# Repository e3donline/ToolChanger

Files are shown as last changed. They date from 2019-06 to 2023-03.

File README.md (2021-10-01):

# ToolChanger
STPs / STLs / DXFs / PDFs

Copyright (C) E3D-Online Ltd (e3d-online.com)
These files are free hardware you can redistribute it and / or
modify it under the terms of the General Public License as
published by the Free Software Foundation, either version 3 of
the License, or (at your option) any later version.

01/10/21 - Added Super Volcano Fan Duct

15/03/21 - Added Hemera Direct Drive Tool Files

10/02/21 - Added Hemera Bowden Brackets

24/02/20 - Added modified V6 Fan Duct STL for Winsinn Fans

05/08/19 - Added README.md to the STLs folders  

31/07/19 - Added step files for printed parts

30/07/19 - Added Volcano PCF Duct

11/07/19 - Added V6 Dock Cables(Mirror)

11/07/19 - Updated V6 PCF Duct

26/06/19 - Added V6 Tool components

25/06/19 - Corrections to TC-FACE

24/06/19 - Intital Upload

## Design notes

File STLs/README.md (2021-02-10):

Print the required number of parts as listed below.

1 x Tool-Changer Cover Body.stl  

      Tool-Changer Cover Dot.stl  
      Tool-Changer Cover Long.stl  
      Tool-Changer Cover Triangle.stl  

1 x X-Carriage Cable Bracket.stl  
1 x X-Carriage Cables.stl   
2 x Hemera Bowden Bracket.stl

Typical slicer settings.  
   
0.20 Layer height.  
0.40 Nozzle.  
3 Perimeters.  
5 Top Layers.  
5 Bottom Layers.  
12% Infil.  

Print with your favourite material.

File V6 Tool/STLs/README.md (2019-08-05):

Print the required number of parts as listed below (for four V6 Bowden Tools).

4 x V6 Cable Support.stl   
4 x V6 PCF Fan Bracket.stl   
4 x V6 Receiver Top.stl   
4 x V6 PCF Duct.stl (Print from Hight-Temperature material).   
2 x V6 Dock Cables(Mirror).stl   
2 x V6 Dock Cables.stl   

Volcano PCF Duct.stl  (Use this fan duct if you are using a Volcano).   

Typical slicer settings.  
   
0.20 Layer height.  
0.40 Nozzle.  
3 Perimeters.  
5 Top Layers.  
5 Bottom Layers.  
12% Infil.  

Print with your favourite material.

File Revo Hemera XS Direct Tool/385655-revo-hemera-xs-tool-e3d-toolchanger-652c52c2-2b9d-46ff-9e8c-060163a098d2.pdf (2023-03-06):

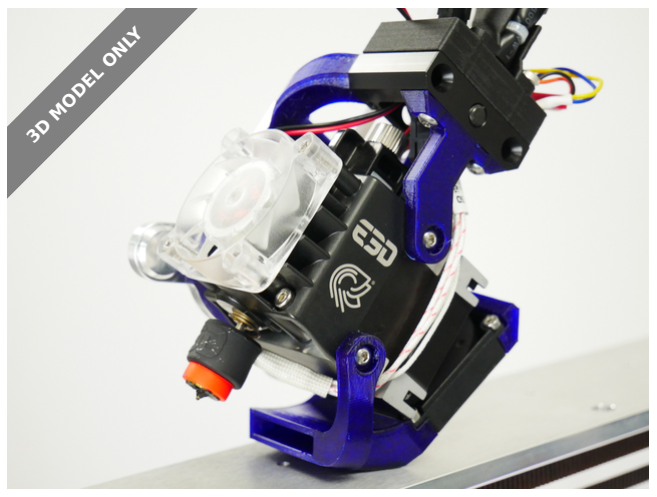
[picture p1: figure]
3D MODEL ONLY

Summary

All the printed parts needed to create the Revo Hemera XS Tool.

3D Printers (https://printables.com/model?categoryId=1) > 3D Printers - Upgrades (https://printables.com/model?categoryId=2)

These are the printable parts for the Revo Hemera XS Tool for E3D's Toolchanger platform.

A mirrored version is provided but be aware, you will lose some build volume in the Y direction (around 10mm) if you choose to use this configuration.

No supports are needed for any of these parts.

Many of the holes need reaming/tapping.

If upgrading from original V6 Hemera tools, please note:

Z offsets have changed by around 11mm from the original V6 Hemera tool so be sure to account for this in your config.g to avoid crashing into the print bed.
The X position of the Toolplate has moved by around 12.5mm to the right. You will need to account for this in your tfree.g and tpre.g files. Note: the offset for the mirrored version will be different.
The Y position of the Toolplate remains the same.

E3D (https://printables.com/social/193579/about)

Revo Hemera XS

Tool - E3D

Toolchanger

VIEW IN BROWSER (https://printables.com/model/385655-revo-hemera-xs-tool-e3d-toolchanger)

updated 27. 2. 2023 | published 27. 2. 2023

•

•

•

### Model files

- Regular Tool | 12 files

blower⁻fan⁻duct.stl

blower⁻fan⁻holder⁻arm.stl

dock-to⁻rhxs.stl

dock-brace.stl

toolplate⁻to⁻rhxs.stl

docking-station.stl

dock-to⁻rhxs.step

blower⁻fan⁻holder⁻arm.step

toolplate⁻to⁻rhxs.step

dock-brace.step

blower⁻fan⁻duct.step

docking-station.step

- Mirrored Tool | 12 files

blower⁻fan⁻duct⁻m.stl

blower⁻fan⁻holder⁻arm⁻m.stl

dock-to⁻rhxs⁻m.stl

dock-brace⁻m.stl

toolplate⁻to⁻rhxs⁻m.stl

docking-station⁻m.stl

blower⁻fan⁻duct⁻m.step

blower⁻fan⁻holder⁻arm⁻m.step

dock-to⁻rhxs⁻m.step

dock-brace⁻m.step

toolplate⁻to⁻rhxs⁻m.step

docking-station⁻m.step

receiver⁻top.stl

License

This work is licensed under a
Creative Commons (4.0 International License)

Attribution⁻ShareAlike (http://creativecommons.org/licenses/by-sa/4.0/)

✖ | Sharing without ATTRIBUTION
✔ | Remix Culture allowed
✔ | Commercial Use
✔ | Free Cultural Works
✔ | Meets Open Definition

cable⁻support.stl

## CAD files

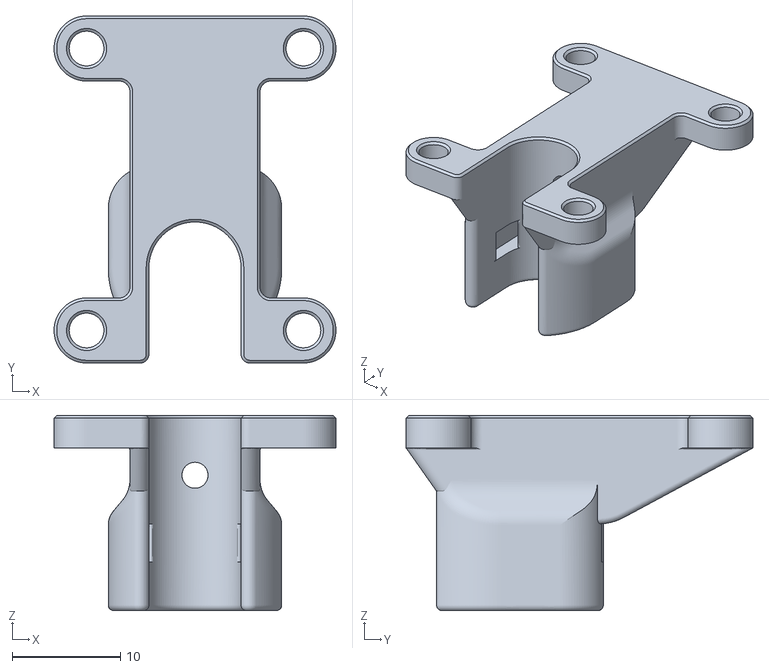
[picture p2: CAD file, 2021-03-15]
Hemera Direct Tool/STLs/V6_Cable_Support.stl
26.0 x 32.0 x 18.0

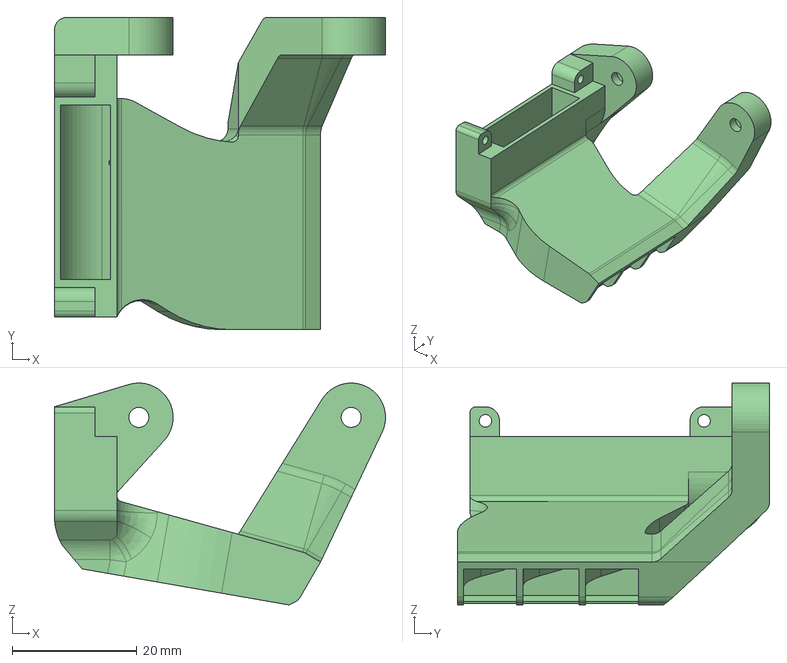
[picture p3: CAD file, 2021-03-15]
Hemera Direct Tool/STPs/Hemera_PCF_Duct_-_Volcano.step
53.0 x 50.0 x 35.5 mm

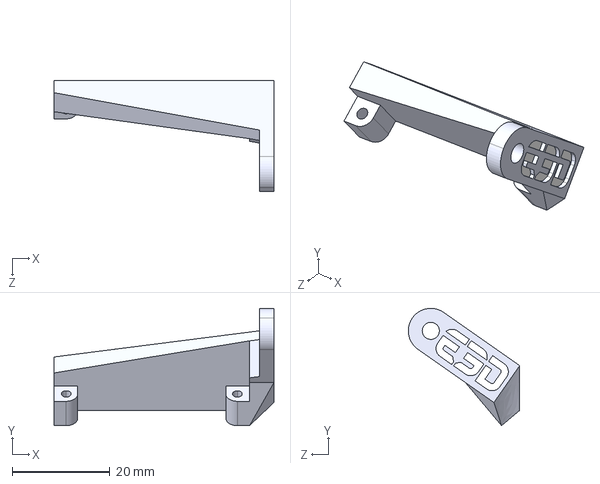
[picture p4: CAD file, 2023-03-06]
Revo Hemera XS Direct Tool/Mirrored Tool/STPs/Blower fan holder arm (M).STEP
45.0 x 24.0 x 22.8 mm

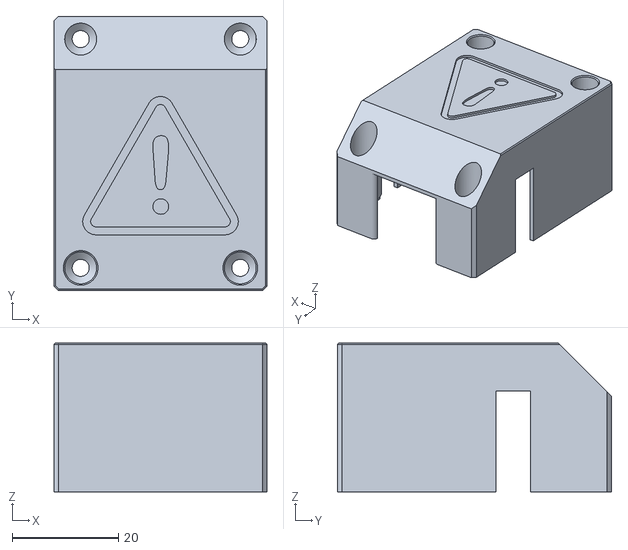
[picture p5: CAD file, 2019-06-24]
STLs/Tool-Changer Cover Body.stl
40.0 x 51.5 x 28.0

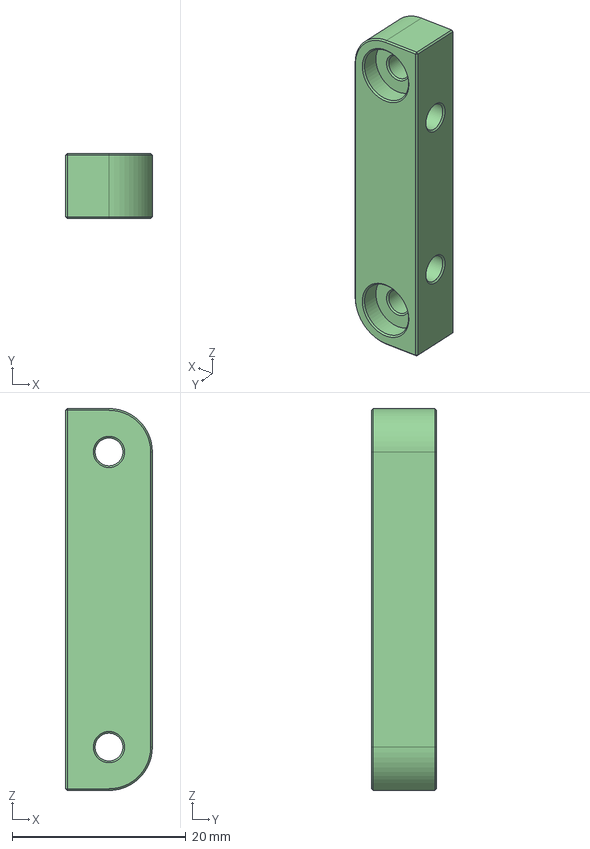
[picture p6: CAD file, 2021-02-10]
STPs/Hemera Bowden Bracket.step
10.0 x 7.50 x 44.0 mm

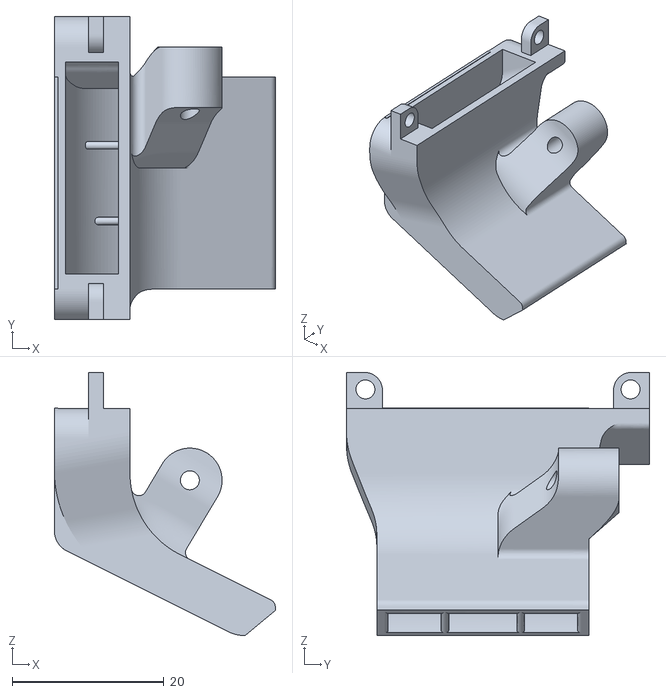
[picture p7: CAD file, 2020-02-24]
V6 Tool/STLs/V6 PCF Duct (Winsinn).stl
29.2 x 40.0 x 34.8

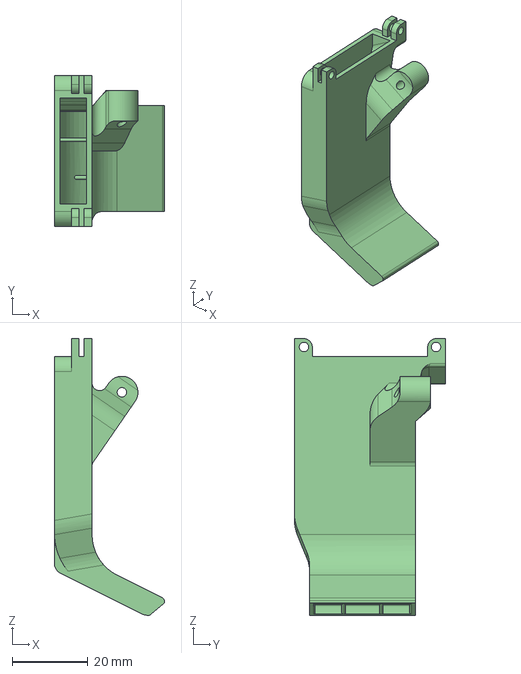
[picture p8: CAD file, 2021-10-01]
V6 Tool/STPs/Super Volcano PCF Duct.step
29.2 x 40.0 x 73.3 mm

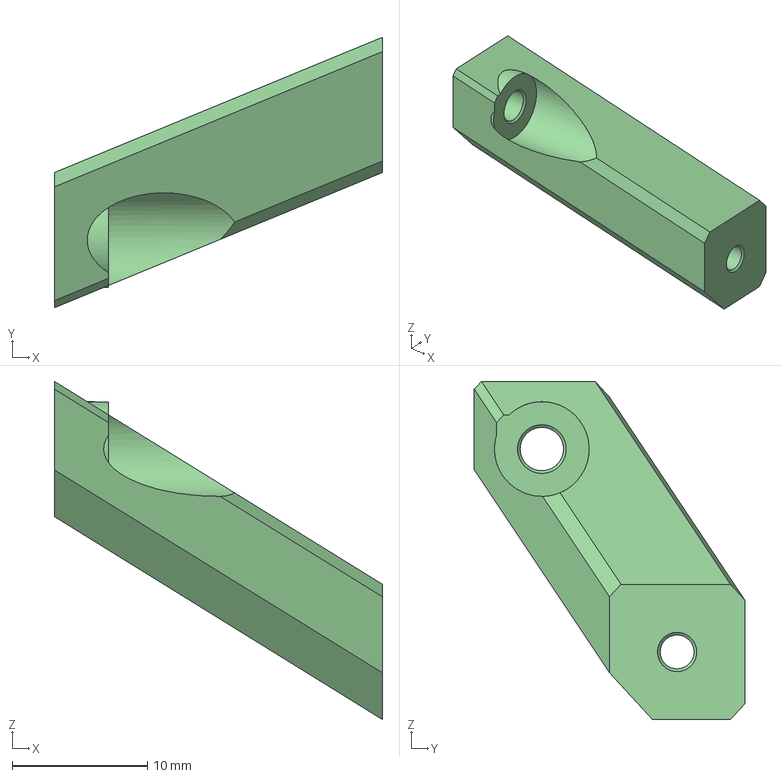
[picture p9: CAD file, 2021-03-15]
Hemera Direct Tool/STPs/TC-V6-HEMERA-DOCK-BRACE.step
24.2 x 20.0 x 25.0 mm

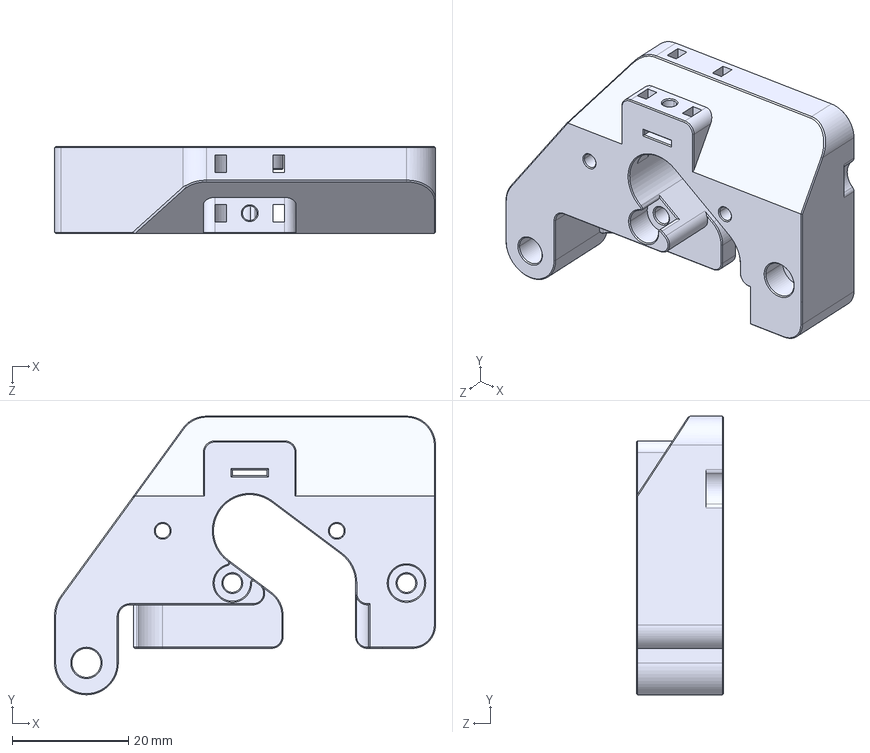
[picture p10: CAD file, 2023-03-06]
Revo Hemera XS Direct Tool/Mirrored Tool/STPs/Docking Station (M).STEP
65.6 x 48.0 x 15.0 mm

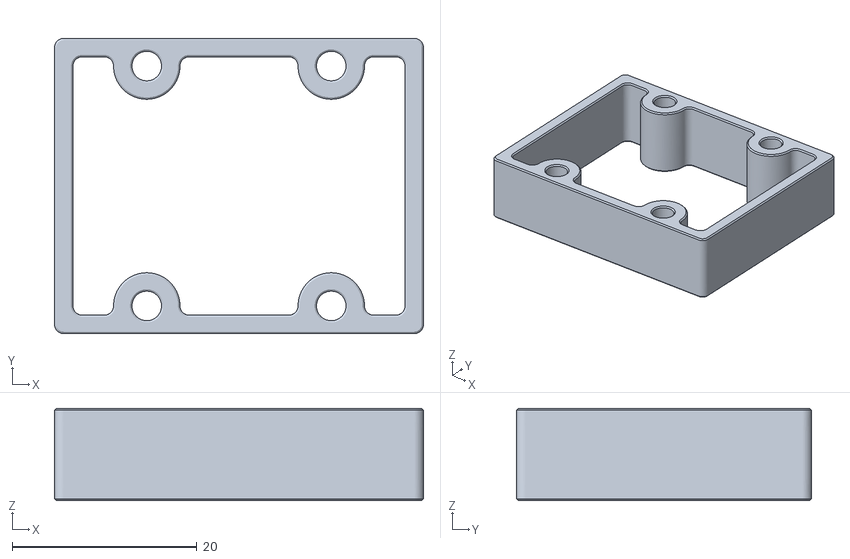
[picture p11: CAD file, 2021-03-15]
Revo Hemera XS Direct Tool/Receiver Top.stl
40.0 x 32.0 x 10.0

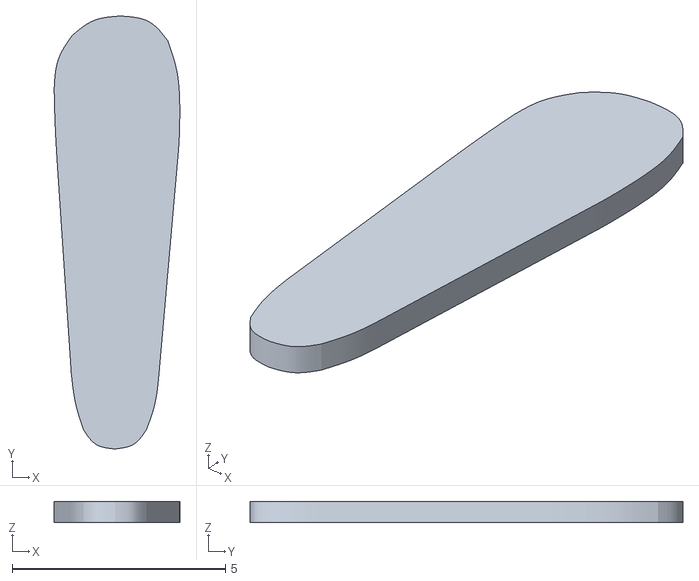
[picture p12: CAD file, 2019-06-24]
STLs/Tool-Changer Cover Long.stl
2.95 x 10.2 x 0.5

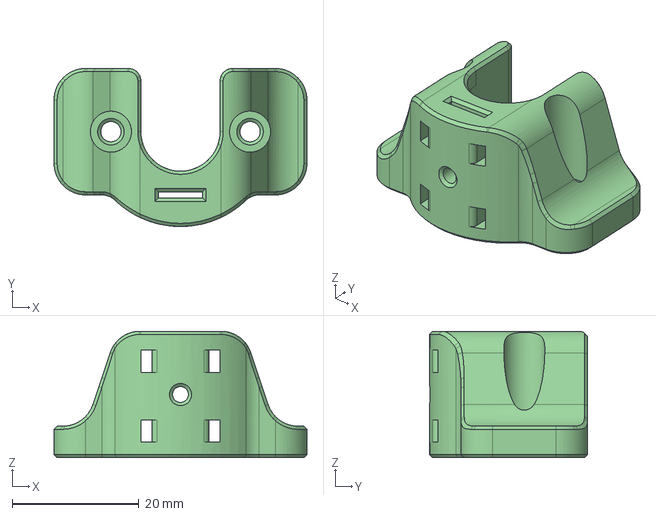
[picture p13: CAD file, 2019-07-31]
STPs/X-Carriage Cable Bracket.step
40.0 x 25.0 x 20.0 mm

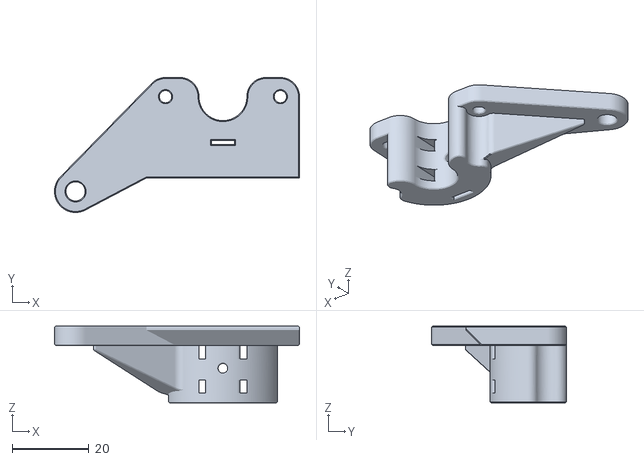
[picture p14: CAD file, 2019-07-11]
V6 Tool/STLs/V6 Dock Cables(Mirror).stl
64.0 x 35.2 x 20.0

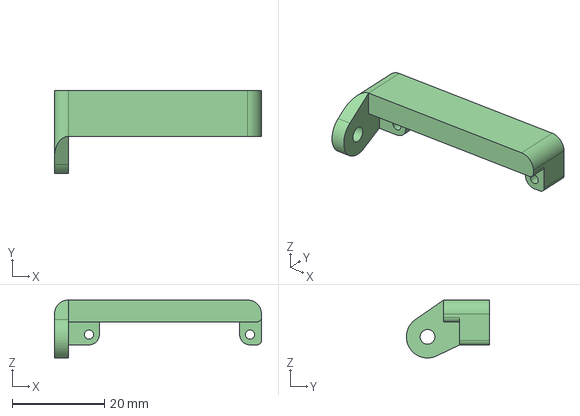
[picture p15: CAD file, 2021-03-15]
Hemera Direct Tool/STPs/Hemera_PCF_Bracket.step
45.0 x 18.1 x 12.6 mm

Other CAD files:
Revo Hemera XS Direct Tool/Cable Support.stl
Revo Hemera XS Direct Tool/Regular Tool/STPs/Blower fan holder arm.STEP
Revo Hemera XS Direct Tool/Regular Tool/STPs/Docking station.STEP
V6 Tool/STPs/V6 Dock Cables.step
Hemera Direct Tool/STLs/Hemera_PCF_Bracket.stl
Hemera Direct Tool/STLs/Hemera_PCF_Duct_-_V6.stl
Hemera Direct Tool/STLs/Hemera_PCF_Duct_-_Volcano.stl
Hemera Direct Tool/STLs/TC-DOCK-V6-DOCK-ADAPTER.stl
Hemera Direct Tool/STLs/TC-HEMERA-PLATE-ADAPTER.stl
Hemera Direct Tool/STLs/TC-V6-DOCK-BRACKET-HEMERA-ADAPTER.stl
Hemera Direct Tool/STLs/TC-V6-HEMERA-DOCK-BRACE-V2.stl
Hemera Direct Tool/STLs/TC-V6-HEMERA-DOCK-BRACE.stl
Hemera Direct Tool/STPs/Hemera_PCF_Duct_-_V6.step
Hemera Direct Tool/STPs/TC-DOCK-V6-DOCK-ADAPTER.step
Hemera Direct Tool/STPs/TC-HEMERA-PLATE-ADAPTER.step
Hemera Direct Tool/STPs/TC-V6-DOCK-BRACKET-HEMERA-ADAPTER.step
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

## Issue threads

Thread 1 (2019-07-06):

Tool Head Face Plate Assembly has wrong dowel pin dimensions

jannau, 2019-07-06:
The dowel pins are listed as `1mm x 4mm`. `10mm x 4mm` seems to match the dimensions of the face plate.

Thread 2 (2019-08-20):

BOM in TC-COUPLER-KIT has errors

nraynaud, 2019-08-20:
- Item 7 is probably 6 M3 standoffs
- Item 8 is probably an error there are probably no M4 screws at all anywhere

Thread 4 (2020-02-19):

V6 PCF Duct does not fit the new pwm ready fan's shipped

arhi, 2020-02-19:
new pwm enable fans shipped as a replacement for old fan's that had issues with pwm have fatter lip and can't fit the existing V6 PCF Duct.stl

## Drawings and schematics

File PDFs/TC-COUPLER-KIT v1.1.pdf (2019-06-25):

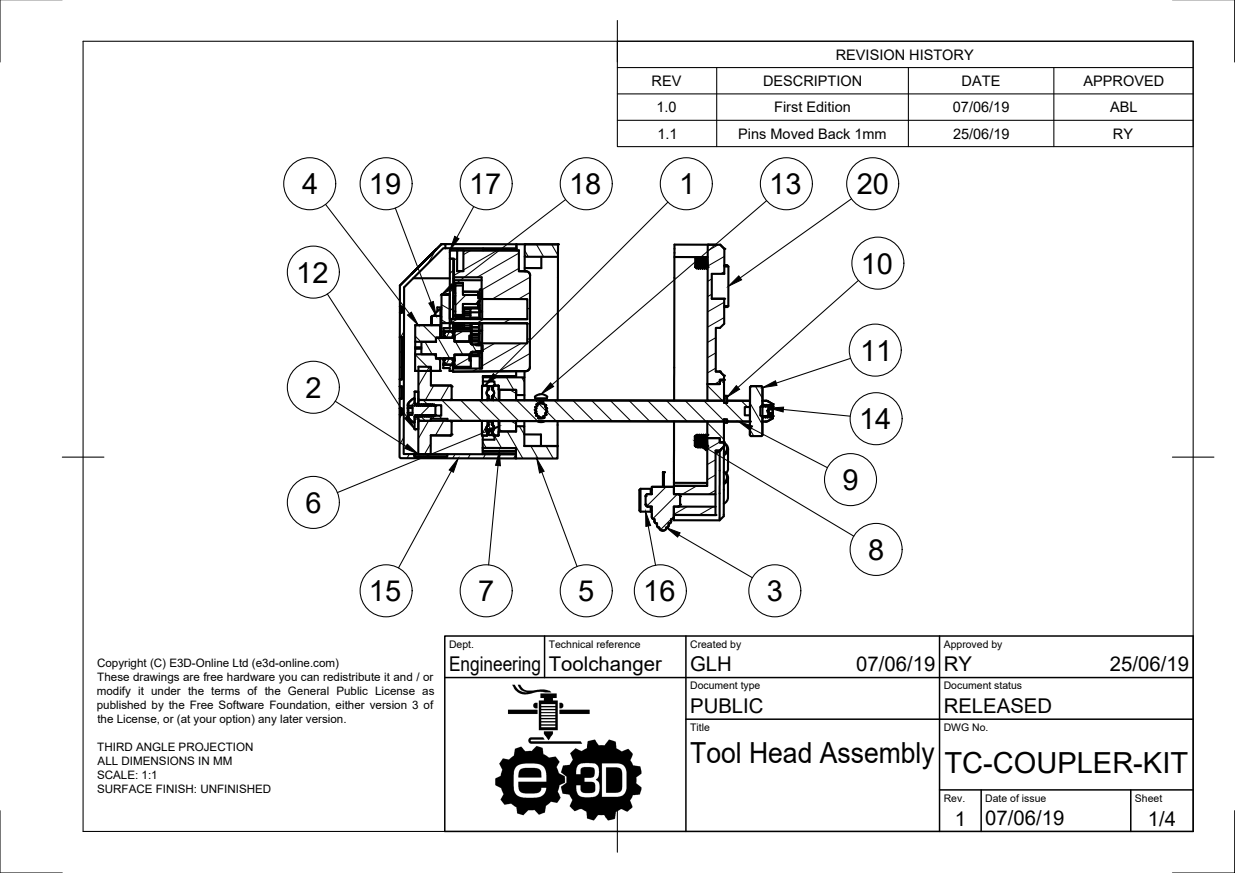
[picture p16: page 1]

REVISION HISTORY

REV | DESCRIPTION | DATE | APPROVED
1.0 | First Edition | 07/06/19 | ABL
1.1 | Pins Moved Back 1mm | 25/06/19 | RY

Dept. Engineering | Technical reference Toolchanger | Created by GLH 07/06/19 | Approved by RY 25/06/19

Copyright (C) E3D-Online Ltd (e3d-online.com)
These drawings are free hardware you can redistribute it and / or modify it under the terms of the General Public License as published by the Free Software Foundation, either version 3 of

Document type PUBLIC | Document status RELEASED

the License, or (at your option) any later version.

Title | DWG No. TC-COUPLER-KIT Tool Head Assembly

THIRD ANGLE PROJECTION
ALL DIMENSIONS IN MM
SCALE: 1:1
SURFACE FINISH: UNFINISHED

Rev. 1 | Date of issue 07/06/19 | Sheet

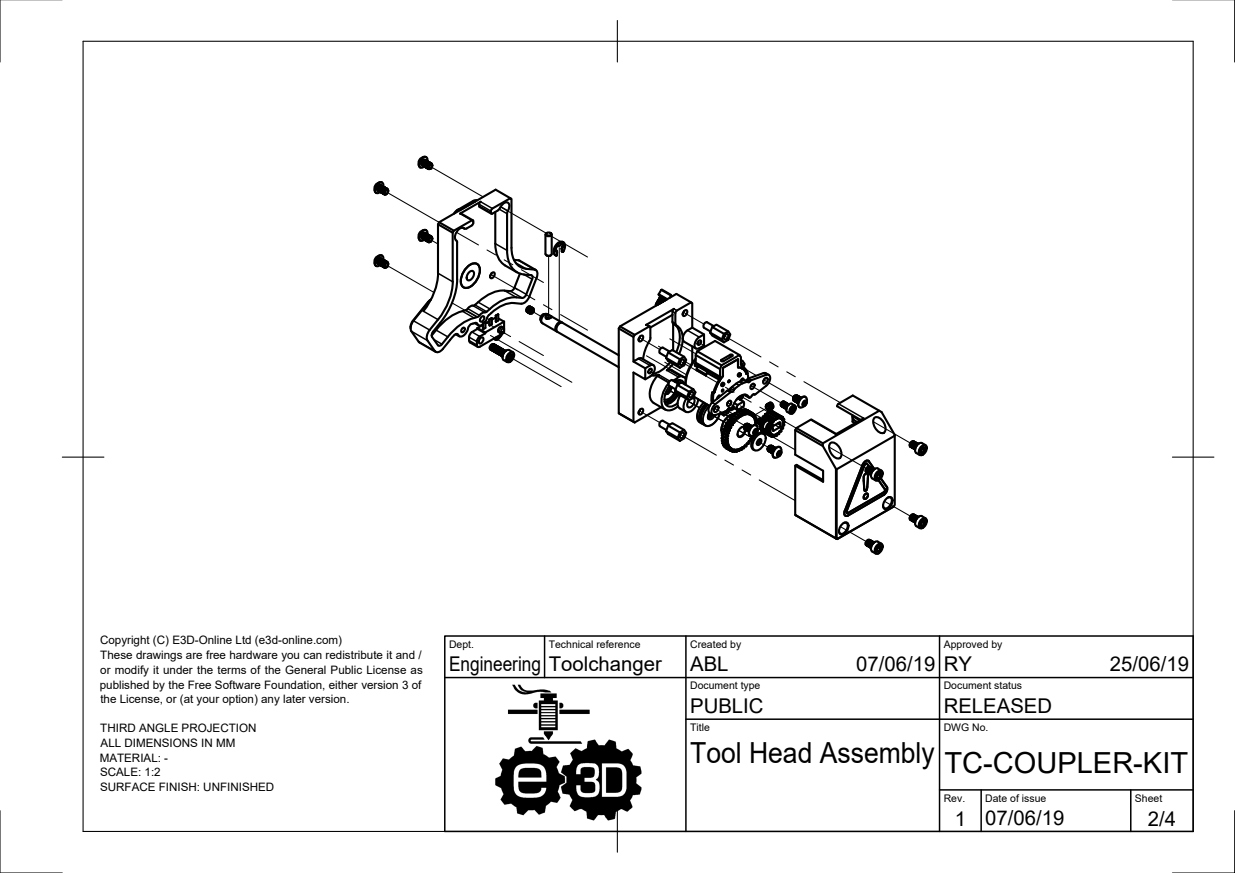
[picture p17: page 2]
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

Dept. Engineering | Technical reference Toolchanger | Created by ABL 07/06/19 | Approved by RY 25/06/19

Document type PUBLIC | Document status RELEASED

the License, or (at your option) any later version.

THIRD ANGLE PROJECTION
ALL DIMENSIONS IN MM
MATERIAL: -
SCALE: 1:2
SURFACE FINISH: UNFINISHED

Title | DWG No. TC-COUPLER-KIT Tool Head Assembly

Rev. | Date of issue | Sheet

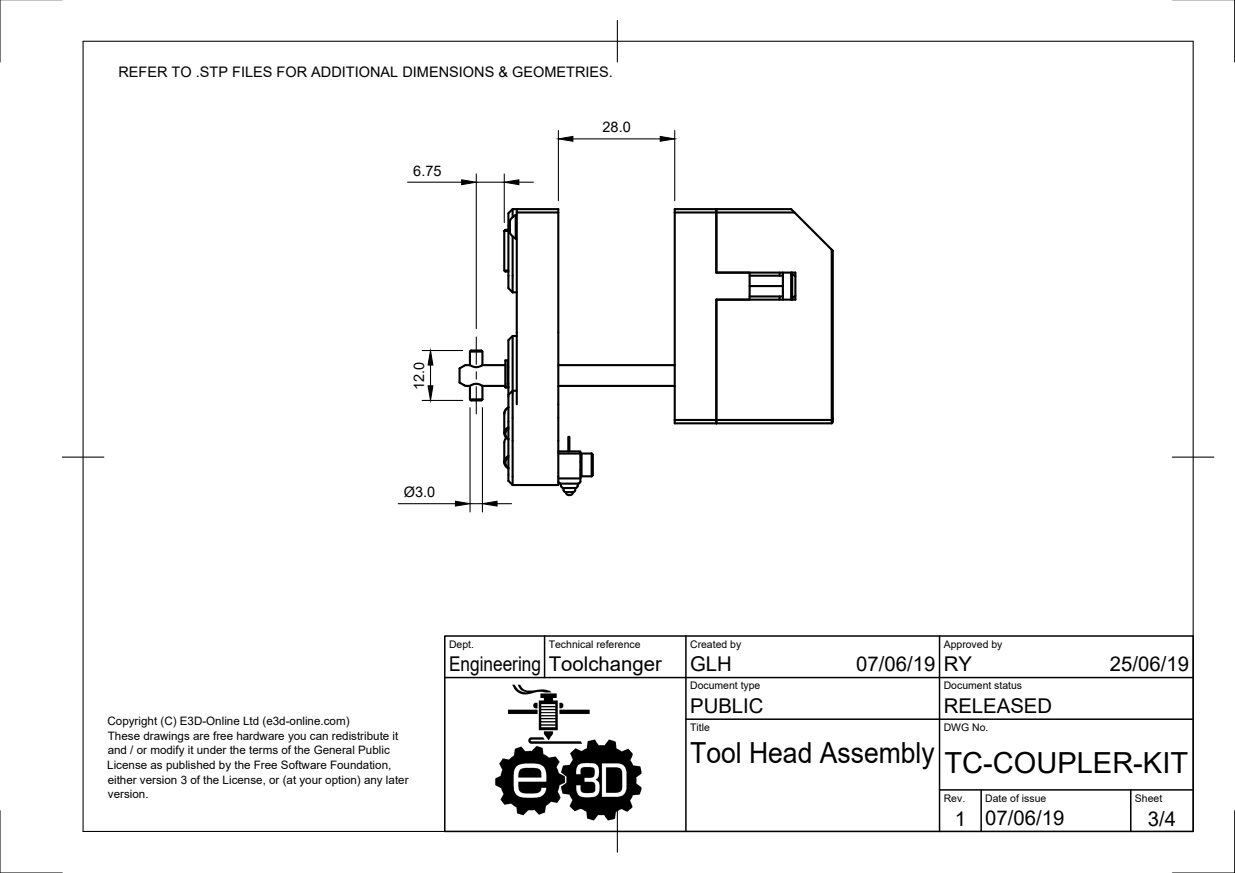
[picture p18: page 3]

REFER TO .STP FILES FOR ADDITIONAL DIMENSIONS & GEOMETRIES.

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

Document type PUBLIC | Document status RELEASED

Copyright (C) E3D-Online Ltd (e3d-online.com)
These drawings are free hardware you can redistribute it
and / or modify it under the terms of the General Public
License as published by the Free Software Foundation,
either version 3 of the License, or (at your option) any later
version.

Title | DWG No. TC-COUPLER-KIT Tool Head Assembly

Rev. | Date of issue | Sheet

Dept. Engineering | Technical reference Toolchanger | Created by GLH 07/06/19 | Approved by RY 25/06/19
| | Document type PUBLIC | Document status RELEASED
| | Title | DWG No. TC-COUPLER-KIT Tool Head Assembly
Rev. | Date of issue | Sheet

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

### Parts List

Item | Qty | Description
1 | 1 | F5-12M Thrust Bearing
2 | 1 | 40T Gear M0D 0.5
3 | 1 | Endstop Switch
4 | 1 | 20T Gear MOD 0.5
5 | 1 | TC-BACK
6 | 1 | MR105RS Bearing
7 | 1 | 8mm Standoff
8 | 7 | M4 5mm Button Head Screw
9 | 1 | Tool Coupler Shaft
10 | 1 | E-Clip
11 | 1 | 12mm x 3mm Dowel Pin
12 | 1 | M3 Washer
13 | 5 | M3 4mm Socket Head Screw
14 | 2 | M3 3mm Grub Screw
15 | 1 | Printed Cover
16 | 1 | M3 10mm Socket Head Screw
17 | 1 | Stepper Motor
18 | 1 | Motor Bracket
19 | 2 | M2.5 5mm Socket Head Screw
20 | 1 | TC-FACE-AS

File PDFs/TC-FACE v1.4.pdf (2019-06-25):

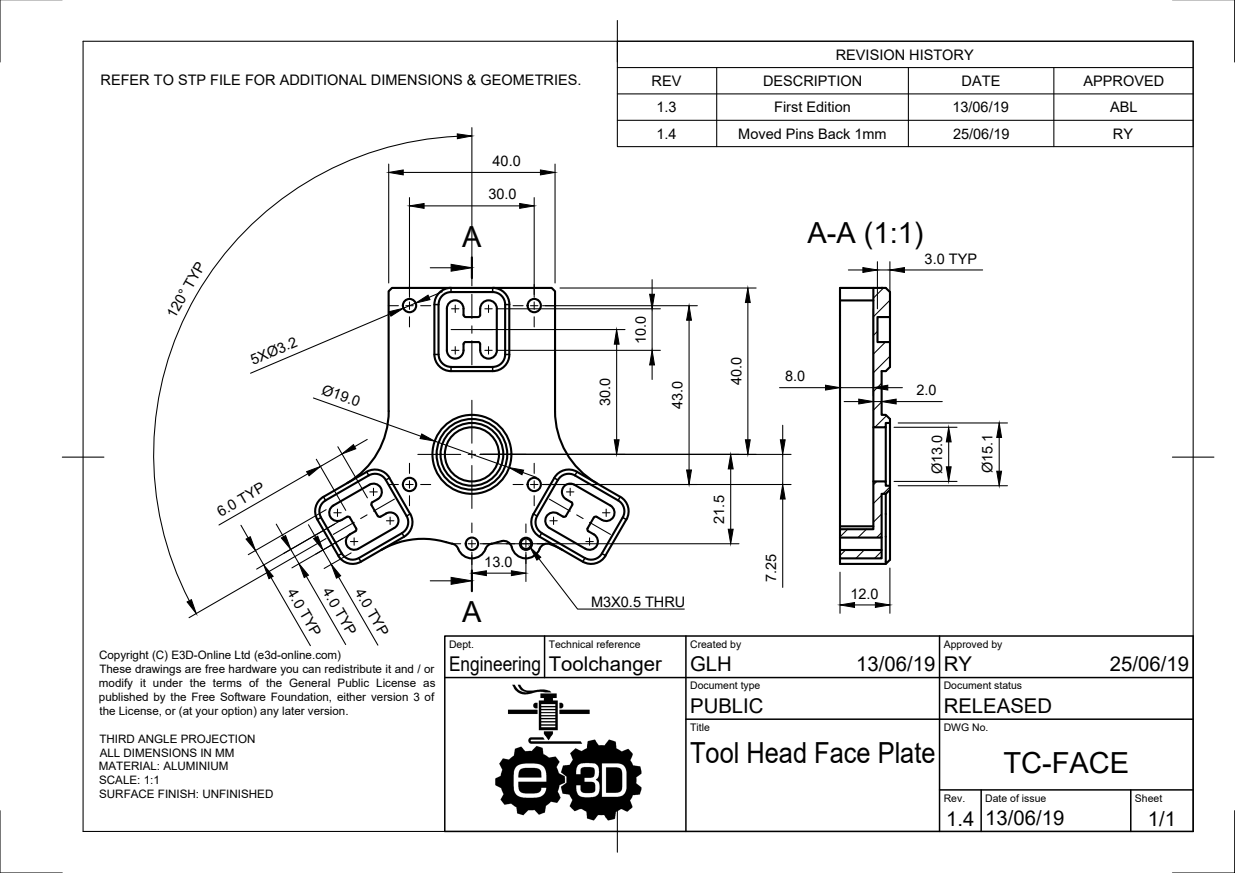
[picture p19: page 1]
M3X0.5 THRU; 120° TYP 43.0 Ø13.0 Ø15.1; 3.0 TYP; 6.0 TYP

REVISION HISTORY

REFER TO STP FILE FOR ADDITIONAL DIMENSIONS & GEOMETRIES.

REV | DESCRIPTION | DATE | APPROVED
1.3 | First Edition | 13/06/19 | ABL
1.4 | Moved Pins Back 1mm | 25/06/19 | RY

4.0 TYP 4.0 TYP 4.0 TYP

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

Dept. Engineering | Technical reference Toolchanger | Created by GLH 13/06/19 | Approved by RY 25/06/19

Document type PUBLIC | Document status RELEASED

the License, or (at your option) any later version.

Title | DWG No. TC-FACE Tool Head Face Plate

THIRD ANGLE PROJECTION
ALL DIMENSIONS IN MM
MATERIAL: ALUMINIUM
SCALE: 1:1
SURFACE FINISH: UNFINISHED

Rev. 1.4 | Date of issue 13/06/19 | Sheet 1/1

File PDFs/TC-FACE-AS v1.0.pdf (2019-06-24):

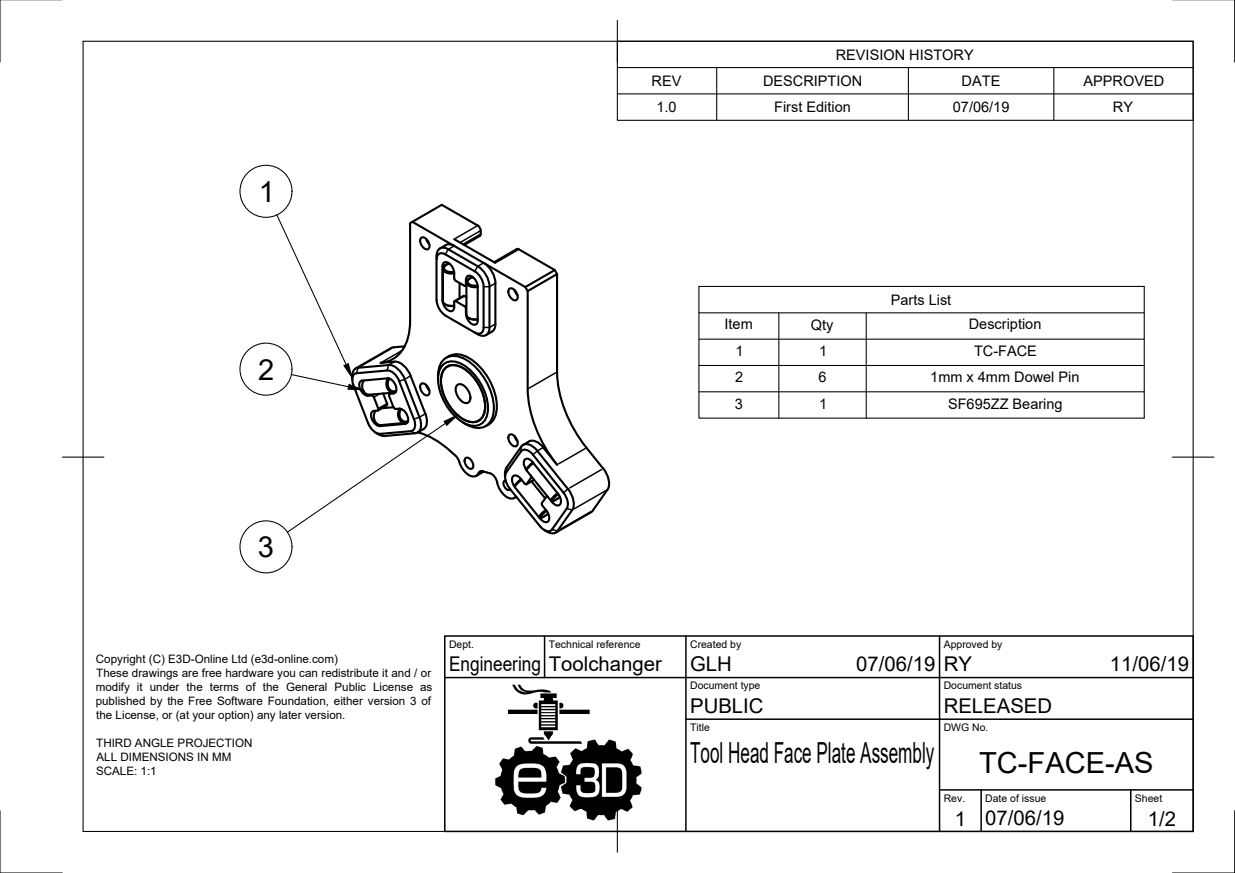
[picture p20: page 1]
Parts List

REVISION HISTORY

REV | DESCRIPTION | DATE | APPROVED
1.0 | First Edition | 07/06/19 | RY

Item | Qty | Description
1 | 1 | TC-FACE
2 | 6 | 1mm x 4mm Dowel Pin
3 | 1 | SF695ZZ Bearing

Dept. Engineering | Technical reference Toolchanger | Created by GLH 07/06/19 | Approved by RY 11/06/19

Copyright (C) E3D-Online Ltd (e3d-online.com)
These drawings are free hardware you can redistribute it and / or modify it under the terms of the General Public License as published by the Free Software Foundation, either version 3 of

Document type PUBLIC | Document status RELEASED

the License, or (at your option) any later version.

Title | DWG No. TC-FACE-AS Tool Head Face Plate Assembly

THIRD ANGLE PROJECTION
ALL DIMENSIONS IN MM
SCALE: 1:1

Rev. 1 | Date of issue 07/06/19 | Sheet 1/2

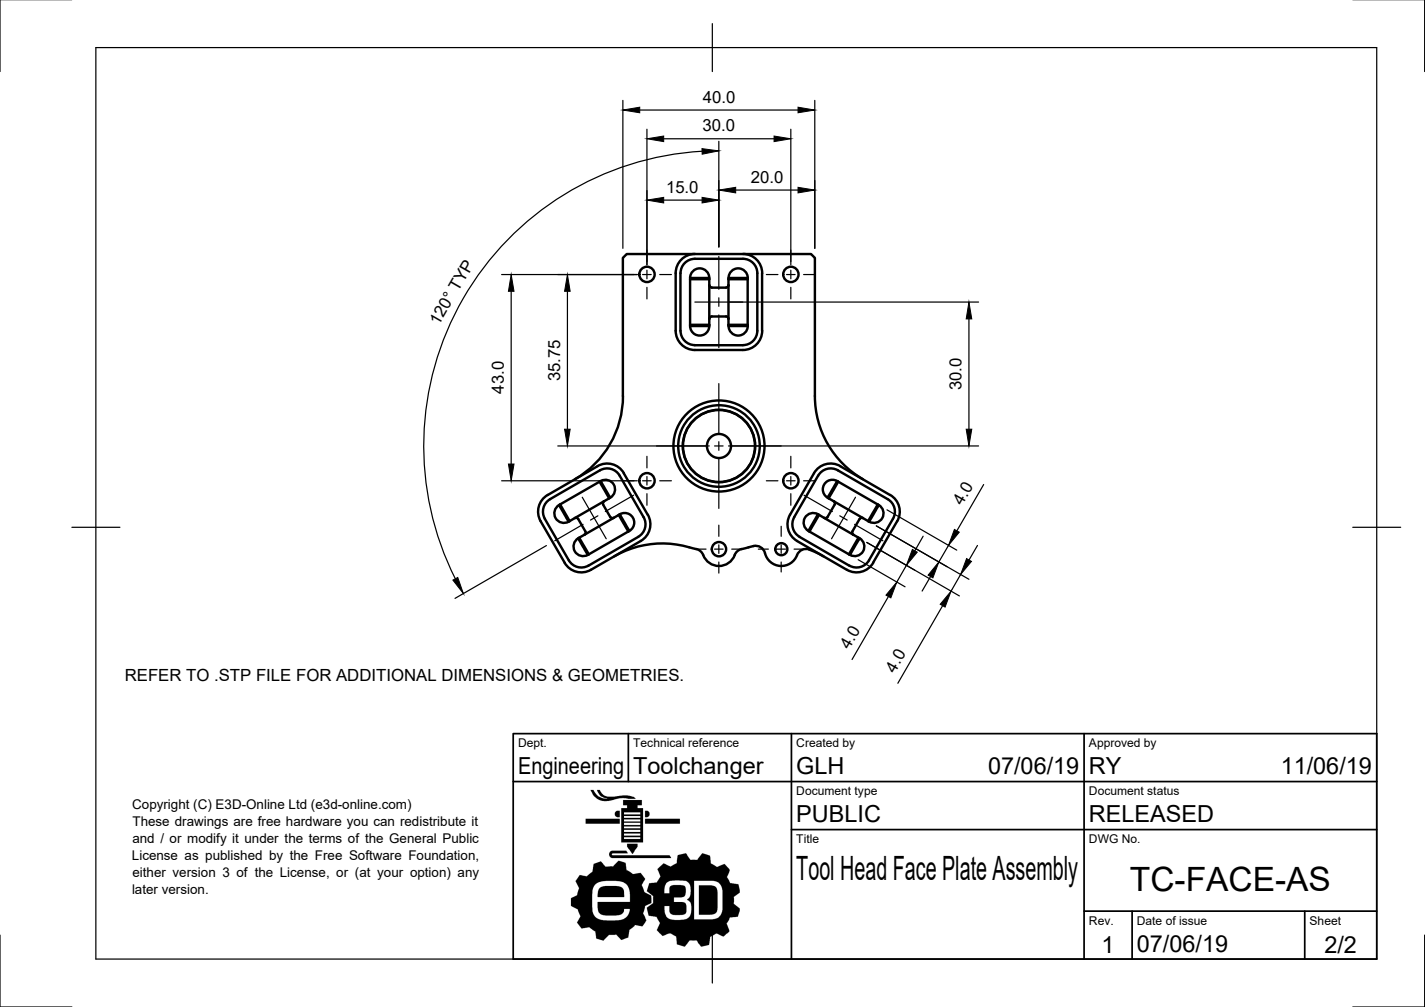
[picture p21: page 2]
120° TYP

REFER TO .STP FILE FOR ADDITIONAL DIMENSIONS & GEOMETRIES.

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

Document type PUBLIC | Document status RELEASED

Copyright (C) E3D-Online Ltd (e3d-online.com)
These drawings are free hardware you can redistribute it
and / or modify it under the terms of the General Public
License as published by the Free Software Foundation,
either version 3 of the License, or (at your option) any
later version.

Title | DWG No. TC-FACE-AS Tool Head Face Plate Assembly

Rev. 1 | Date of issue 07/06/19 | Sheet 2/2

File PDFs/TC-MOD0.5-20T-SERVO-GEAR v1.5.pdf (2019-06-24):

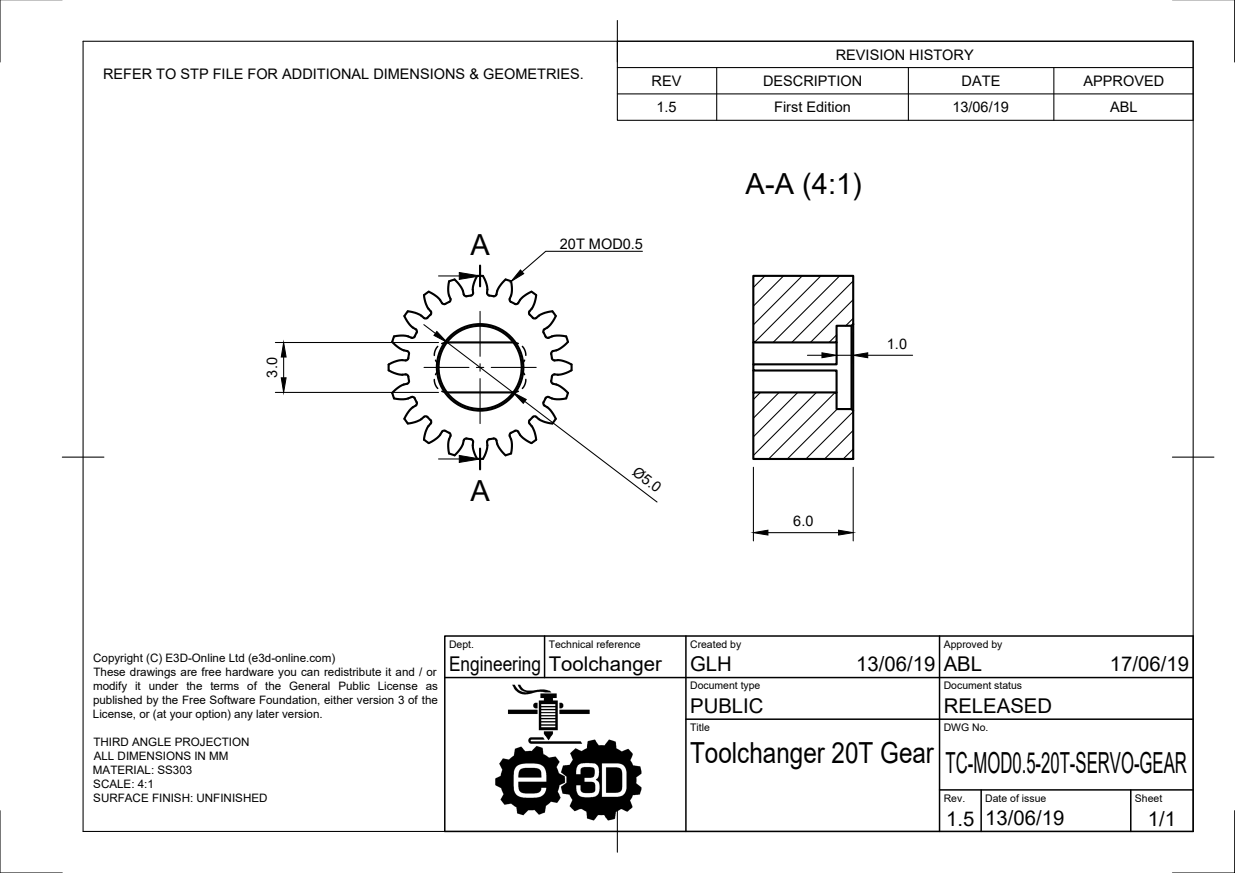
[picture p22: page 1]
20T MOD0.5

REVISION HISTORY

REFER TO STP FILE FOR ADDITIONAL DIMENSIONS & GEOMETRIES.

REV | DESCRIPTION | DATE | APPROVED
1.5 | First Edition | 13/06/19 | ABL

Dept. Engineering | Technical reference Toolchanger | Created by GLH 13/06/19 | Approved by ABL 17/06/19

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

Document type PUBLIC | Document status RELEASED

License, or (at your option) any later version.

Title | DWG No. TC-MOD0.5-20T-SERVO-GEAR Toolchanger 20T Gear

THIRD ANGLE PROJECTION
ALL DIMENSIONS IN MM
MATERIAL: SS303
SCALE: 4:1
SURFACE FINISH: UNFINISHED

Rev. 1.5 | Date of issue 13/06/19 | Sheet 1/1

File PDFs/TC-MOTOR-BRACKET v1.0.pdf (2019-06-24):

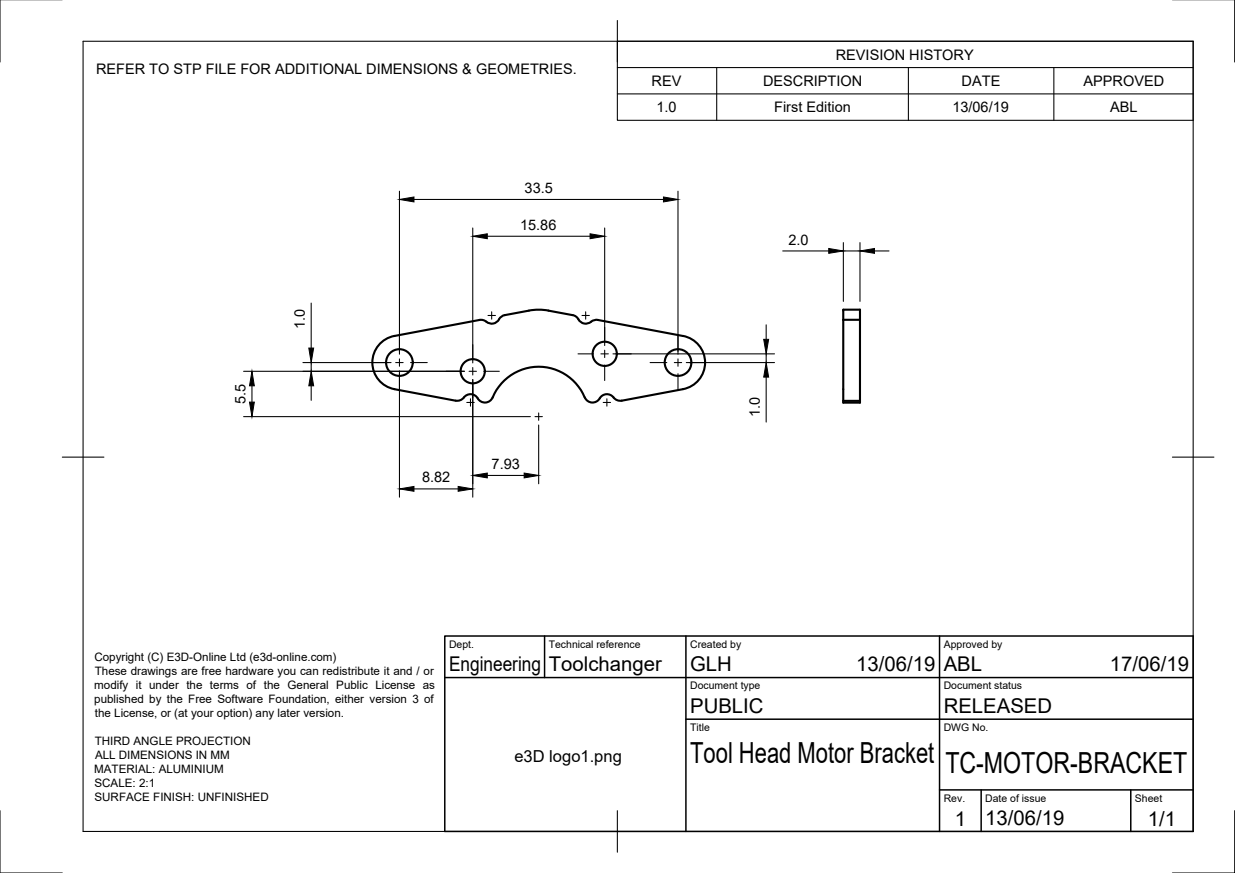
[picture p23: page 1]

REVISION HISTORY

REFER TO STP FILE FOR ADDITIONAL DIMENSIONS & GEOMETRIES.

REV | DESCRIPTION | DATE | APPROVED
1.0 | First Edition | 13/06/19 | ABL

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

e3D logo1.png | | Document type PUBLIC | Document status RELEASED

the License, or (at your option) any later version.

Title | DWG No. TC-MOTOR-BRACKET Tool Head Motor Bracket

THIRD ANGLE PROJECTION
ALL DIMENSIONS IN MM
MATERIAL: ALUMINIUM
SCALE: 2:1
SURFACE FINISH: UNFINISHED

Rev. 1 | Date of issue 13/06/19 | Sheet 1/1

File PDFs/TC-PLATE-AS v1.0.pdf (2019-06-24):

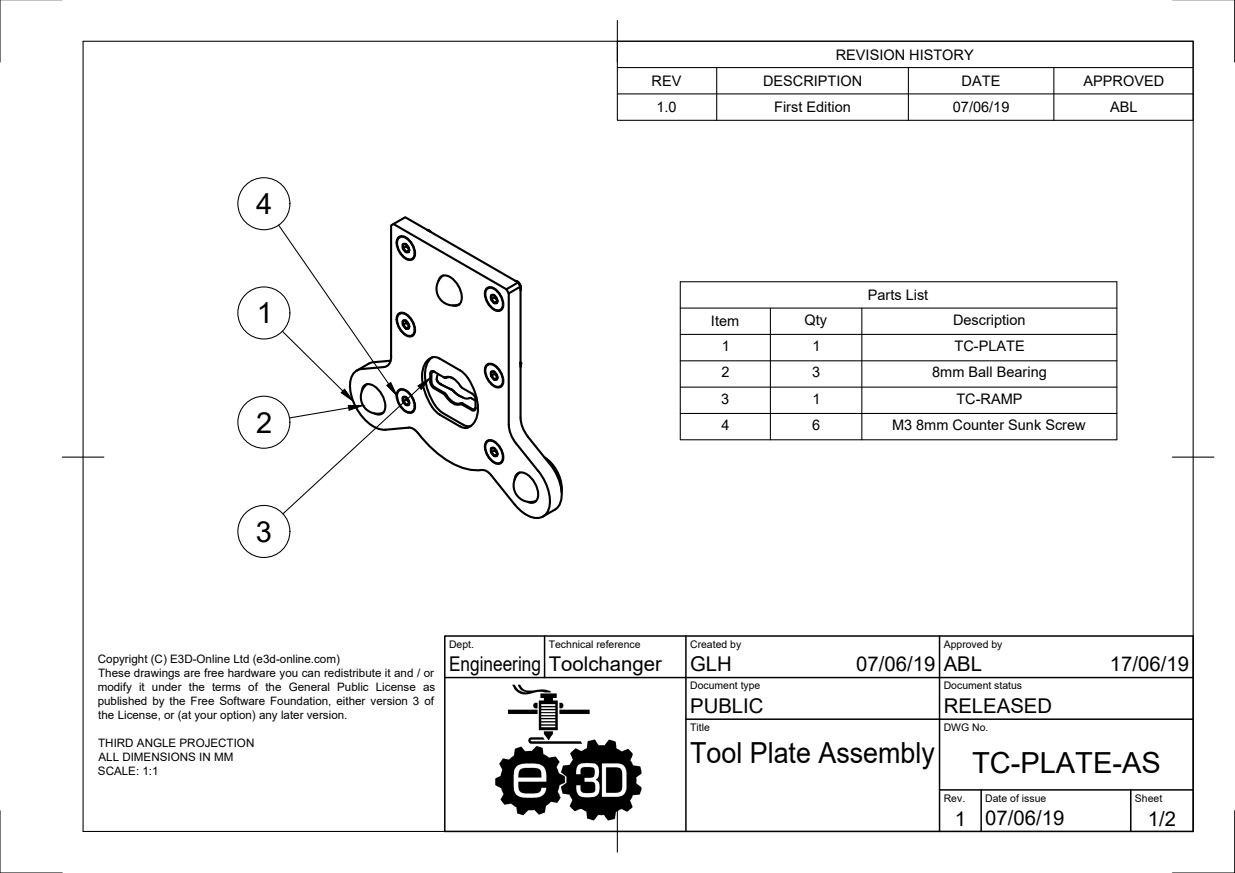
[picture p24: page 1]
Parts List

REVISION HISTORY

REV | DESCRIPTION | DATE | APPROVED
1.0 | First Edition | 07/06/19 | ABL

Item | Qty | Description
1 | 1 | TC-PLATE
2 | 3 | 8mm Ball Bearing
3 | 1 | TC-RAMP
4 | 6 | M3 8mm Counter Sunk Screw

Dept. Engineering | Technical reference Toolchanger | Created by GLH 07/06/19 | Approved by ABL 17/06/19

Copyright (C) E3D-Online Ltd (e3d-online.com)
These drawings are free hardware you can redistribute it and / or modify it under the terms of the General Public License as published by the Free Software Foundation, either version 3 of

Document type PUBLIC | Document status RELEASED

the License, or (at your option) any later version.

Title | DWG No. TC-PLATE-AS Tool Plate Assembly

THIRD ANGLE PROJECTION
ALL DIMENSIONS IN MM
SCALE: 1:1

Rev. 1 | Date of issue 07/06/19 | Sheet 1/2

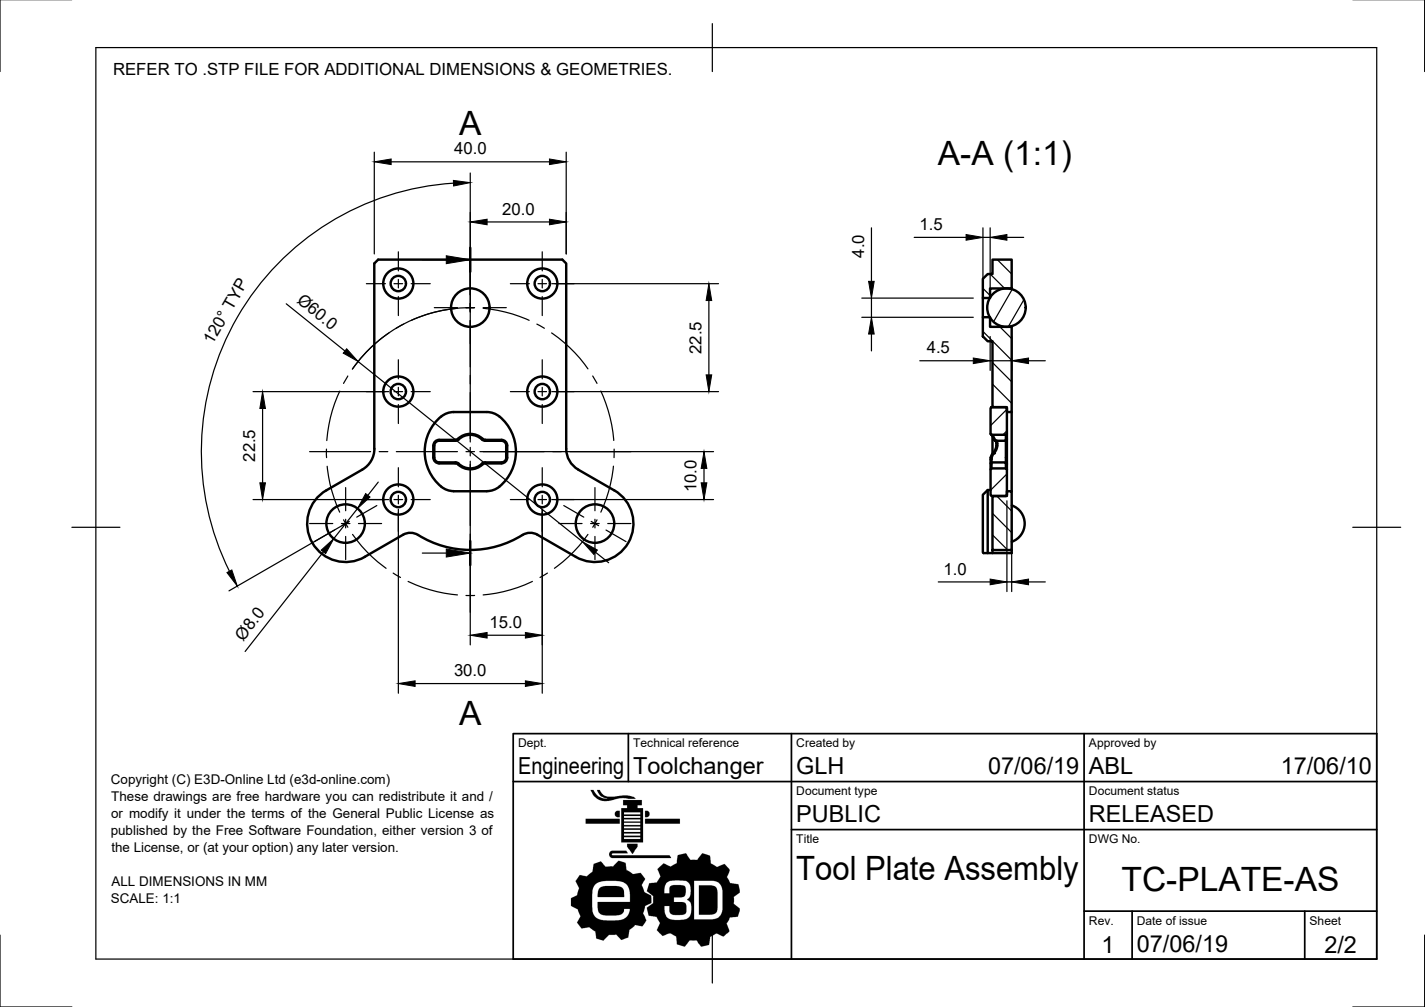
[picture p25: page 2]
Ø60.0 120° TYP

REFER TO .STP FILE FOR ADDITIONAL DIMENSIONS & GEOMETRIES.

Dept. Engineering | Technical reference Toolchanger | Created by GLH 07/06/19 | Approved by ABL Copyright (C) E3D-Online Ltd (e3d-online.com) 17/06/10

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

Document type PUBLIC | Document status RELEASED

the License, or (at your option) any later version.

Title | DWG No. TC-PLATE-AS Tool Plate Assembly

ALL DIMENSIONS IN MM
SCALE: 1:1

Rev. 1 | Date of issue 07/06/19 | Sheet 2/2

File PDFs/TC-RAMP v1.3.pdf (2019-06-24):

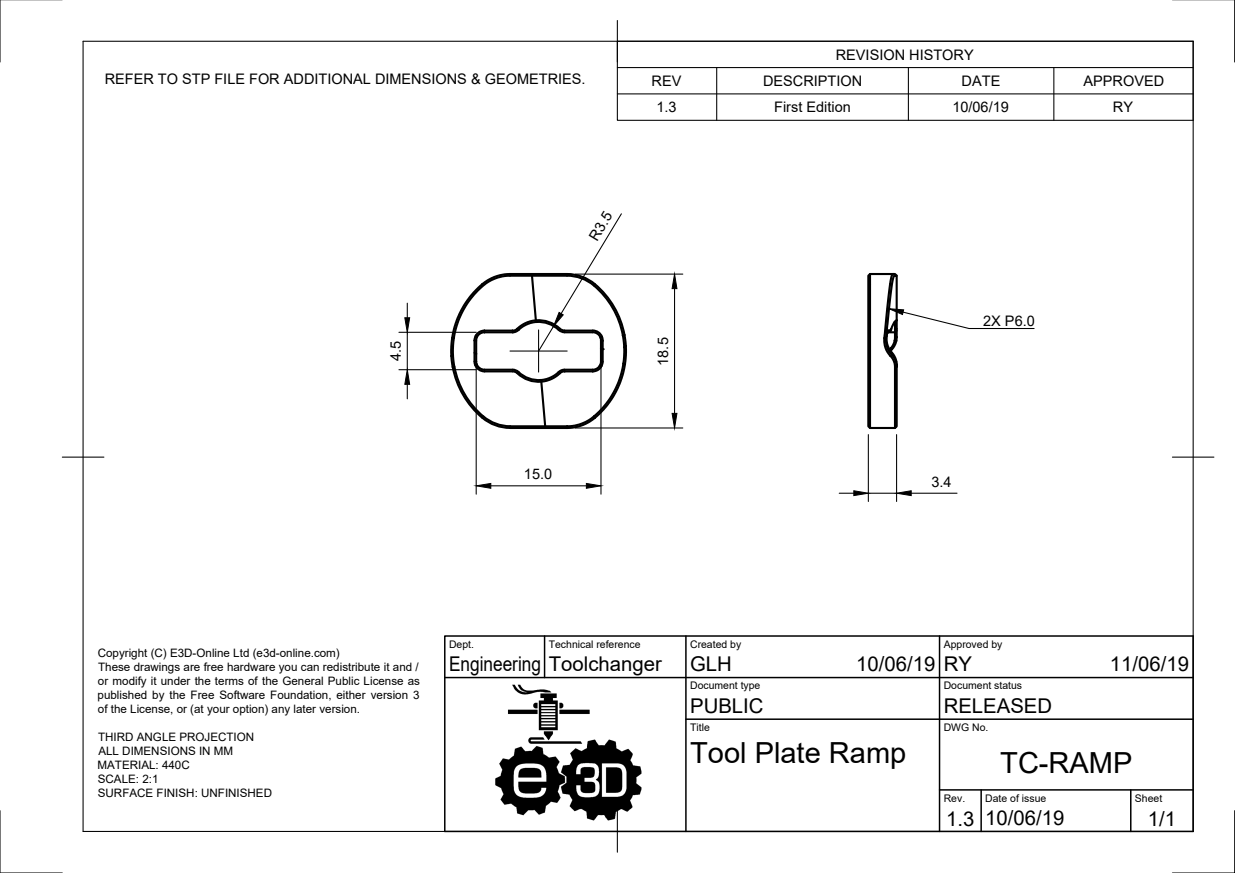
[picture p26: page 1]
REFER TO STP FILE FOR ADDITIONAL DIMENSIONS & GEOMETRIES.

REVISION HISTORY

REV | DESCRIPTION | DATE | APPROVED
1.3 | First Edition | 10/06/19 | RY

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

Dept. Engineering | Technical reference Toolchanger | Created by GLH 10/06/19 | Approved by RY 11/06/19

Document type PUBLIC | Document status RELEASED

of the License, or (at your option) any later version.

THIRD ANGLE PROJECTION
ALL DIMENSIONS IN MM
MATERIAL: 440C
SCALE: 2:1
SURFACE FINISH: UNFINISHED

Title | DWG No. TC-RAMP Tool Plate Ramp

Rev. 1.3 | Date of issue 10/06/19 | Sheet 1/1

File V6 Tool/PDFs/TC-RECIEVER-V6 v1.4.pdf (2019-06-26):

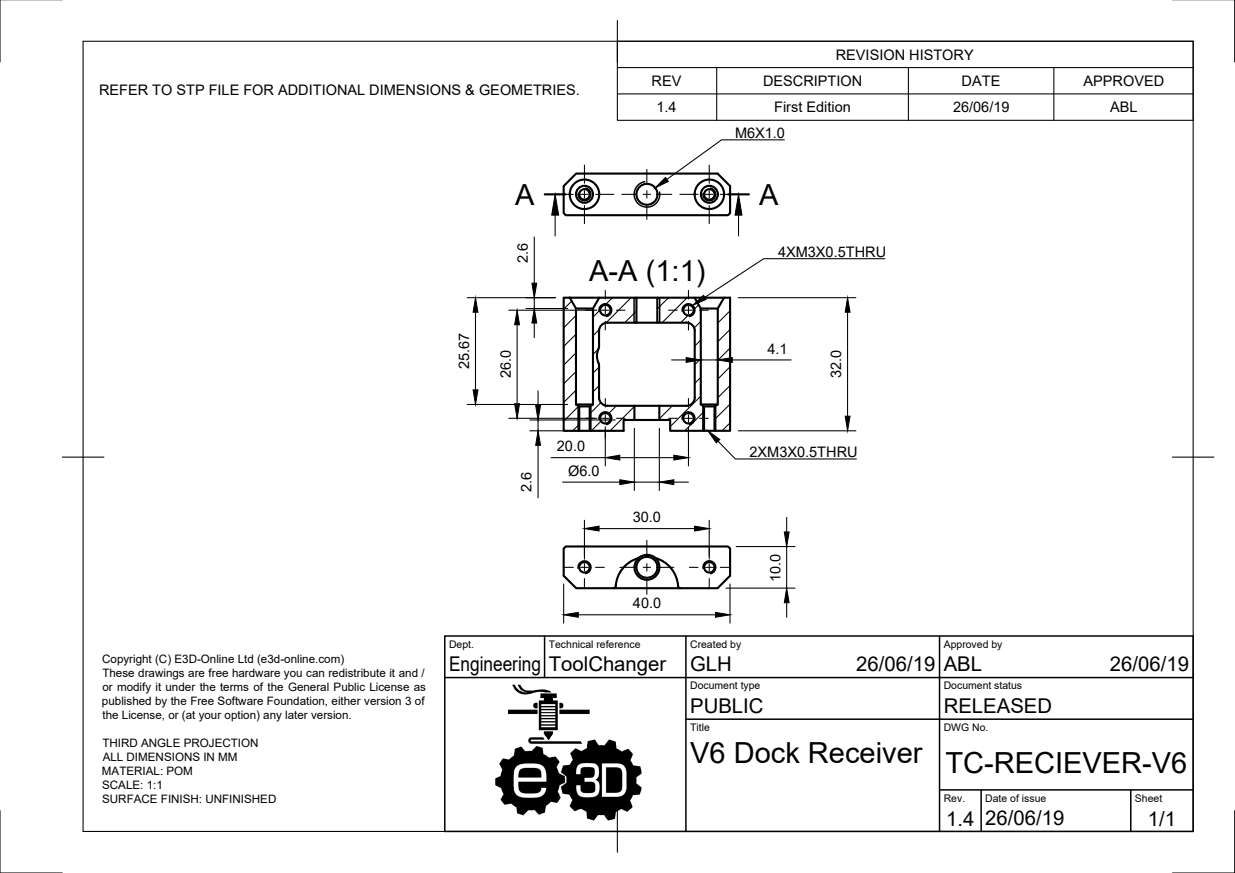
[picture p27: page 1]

REVISION HISTORY

REV | DESCRIPTION | DATE | APPROVED
1.4 | First Edition | 26/06/19 | ABL

REFER TO STP FILE FOR ADDITIONAL DIMENSIONS & GEOMETRIES.

Dept. Engineering | Technical reference ToolChanger | Created by GLH 26/06/19 | Approved by ABL 26/06/19

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

Document type PUBLIC | Document status RELEASED

the License, or (at your option) any later version.

Title | DWG No. TC-RECIEVER-V6 V6 Dock Receiver

THIRD ANGLE PROJECTION
ALL DIMENSIONS IN MM
MATERIAL: POM
SCALE: 1:1
SURFACE FINISH: UNFINISHED

Rev. 1.4 | Date of issue 26/06/19 | Sheet 1/1

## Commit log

2021-02-10 Hemera Bowden Brackets
    [Hemera Bowden Bracket.stl]
2023-03-06 Add Revo Hemera XS Direct Tool
    [Blower fan duct (M).STEP, Blower fan duct (M).STL, Blower fan duct.STEP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]
